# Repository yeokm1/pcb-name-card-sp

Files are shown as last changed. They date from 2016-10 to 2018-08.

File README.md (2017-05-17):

# pcb-name-card-sp

My name or business card that is on a Printed Circuit Board (PCB). Comes with an white LED, UV LED and a ruler. Not forgetting a QR code containing my contact details in [Vcard](https://en.wikipedia.org/wiki/VCard) format. This is an update to my [previous version](https://github.com/yeokm1/pcb-name-card) since I have changed my company.

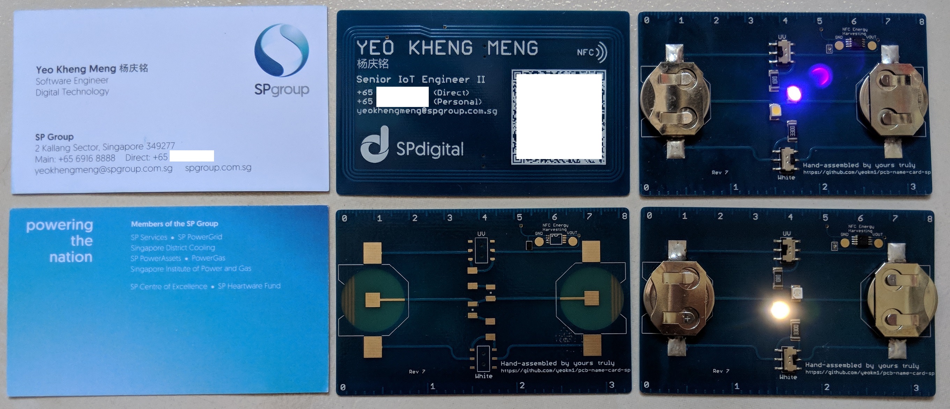
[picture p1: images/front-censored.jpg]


### PCB Design software and addons/references used

1. Eagle 8.0.2
2. Modified CR2032 library based on [here](https://github.com/nickaknudson/eagle-nickaknudson/blob/master/cr2032.lbr)
2. Elecrow Design Rule Check for 2 layers (in repo as `Elecrow_2-layer_eagle_rule.dru`)
3. Elecrow Gerber Generater 2-layer board (in repo as `Elecrow_Gerber_Generater_DrillAlign.cam`)
4. QR code generated from [here](http://goqr.me/)

### Schematic drawings

Image are exported from Eagle at 600dpi.

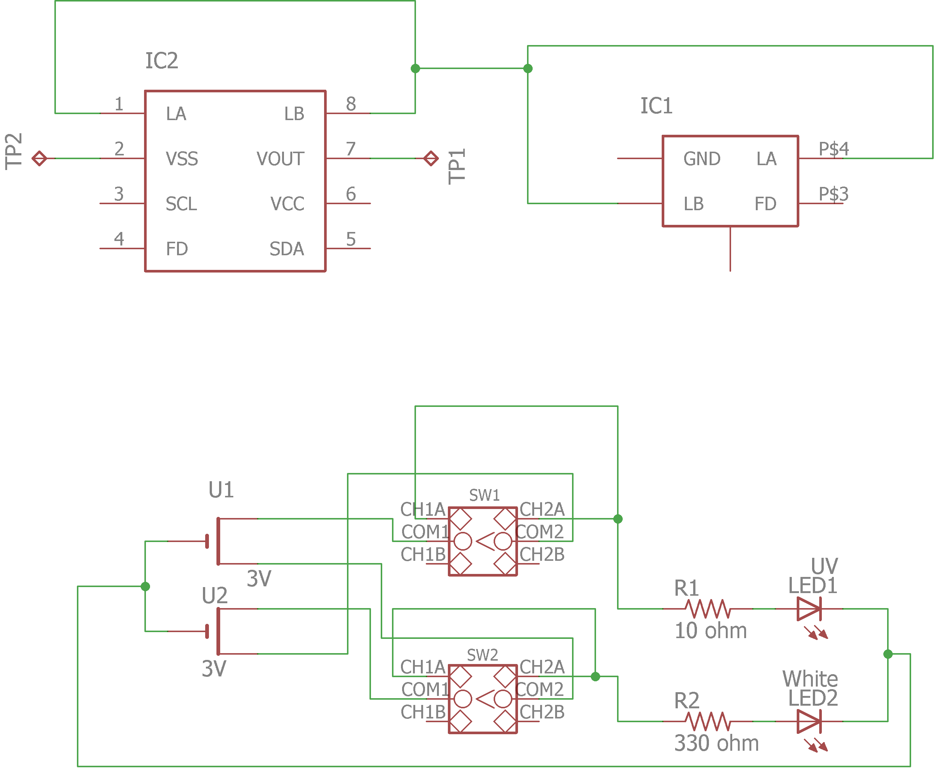
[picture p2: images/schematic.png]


The board schematic as seen in Eagle. The connections are slightly convoluted to prevent the traces from crossing in the board layout.

### Bill of Materials (BOM) for components only

Assume minimum order 10 pieces, cost in Singapore dollars. There are additional savings if I order more say 50 units but the savings are still small. Delivery for BOM not included.

The BOM is available in the odt spreadsheets in this repo.

### PCB fabrication

PCB fabrication is currently done by [Elecrow (10-pieces-link)](http://www.elecrow.com/10pcs-2-layer-pcb-p-1175.html) or [(50-pieces-link)](http://www.elecrow.com/50pcs-2-layer-pcb-enig-p-1172.html) based on the following settings. Remember to consult the order submission specifications at the bottom of the previous link before submitting. Use the provided Gerber generator to produce the Gerber files.

#### My Fabrication Settings:

1. Layer: 2
2. PCB Thickness: 0.6mm
3. Copper Weight : 1oz 35um (NA for 50 pieces)
4. PCB Size : 10cm Max * 10cm Max (or 50cm2 for 50 pieces)
5. PCB Color : Blue
6. Surface Finish: ENIG
7. PCB Stencil : NO Stencil
8. Lead time : Shipped in 4 to 7 days (NA for 50 pieces)
9. Panelizing : Single PCB with milling

# References
1. [How to design a 13.56 MHz
customized tag antenna](http://www.st.com/st-web-ui/static/active/jp/resource/technical/document/application_note/CD00221490.pdf)
2. [The impact of high pulse drain on CR2032 coin-cell battery capacity](http://m.eet.com/media/1121454/c0924post.pdf)
3. [Panasonic NFC Design Navigator](http://www.semicon.panasonic.co.jp/en/tool/nfcdesignnavigator/)

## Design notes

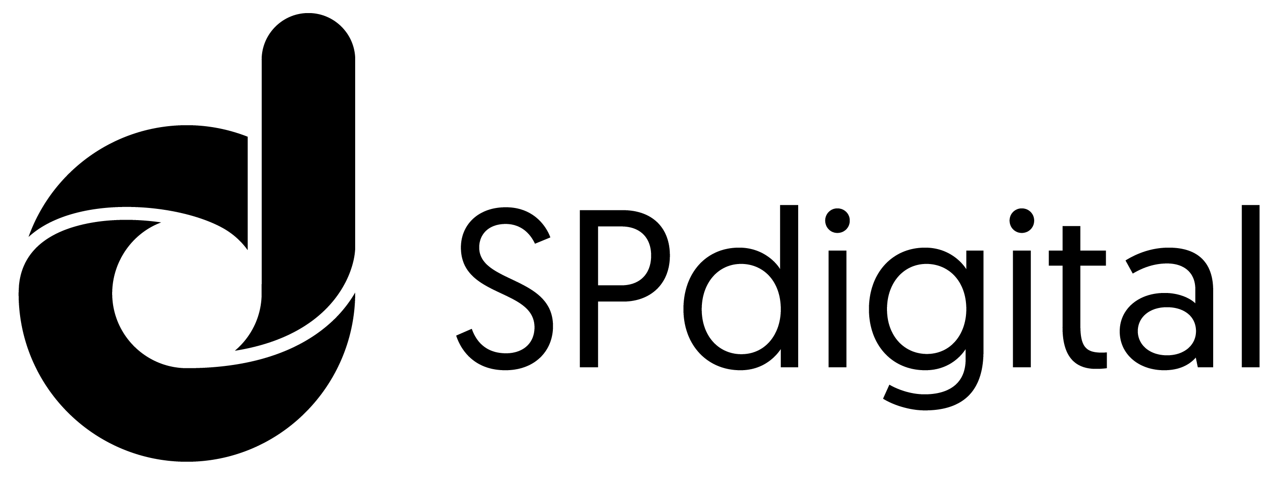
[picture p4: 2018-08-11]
sp-designs-rebrand/sp-digital.png

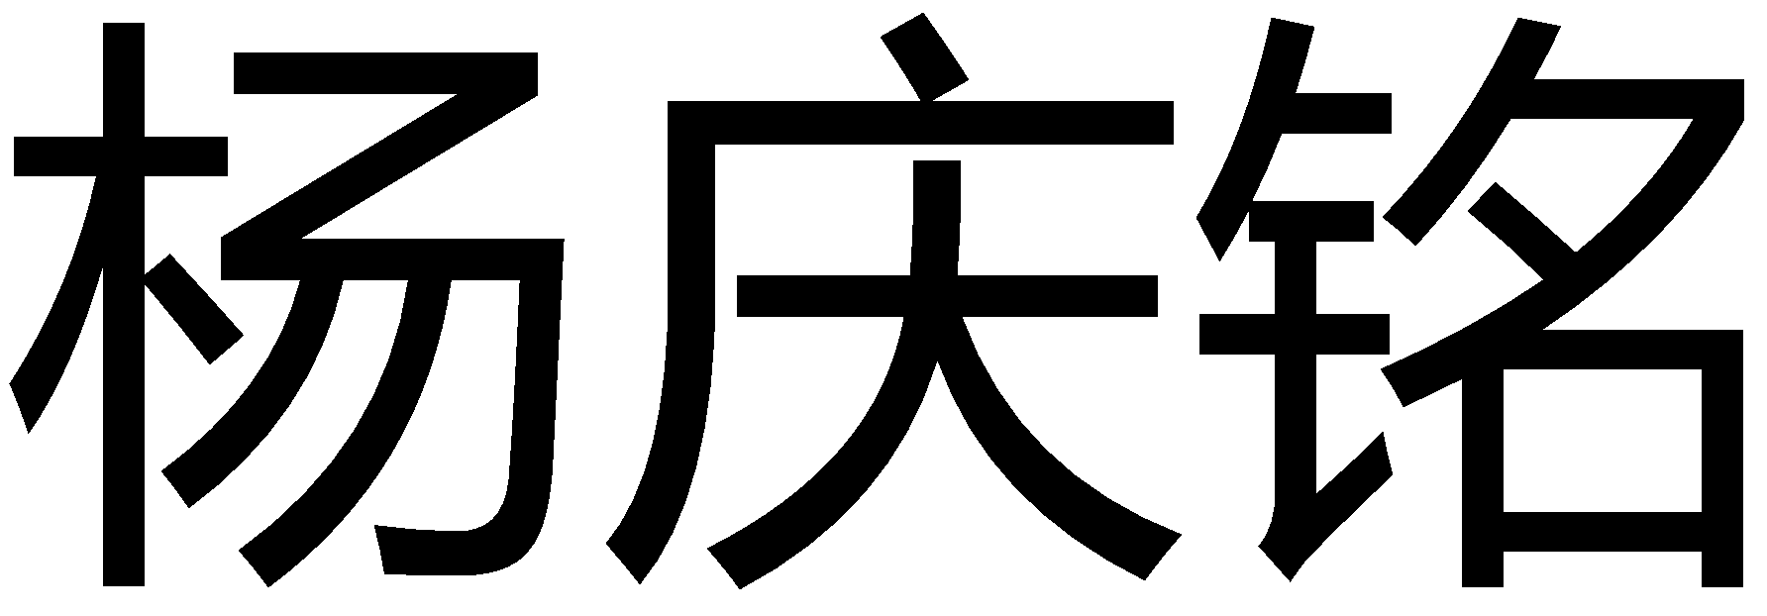
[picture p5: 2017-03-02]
sp-designs-rebrand/chinese-name.bmp

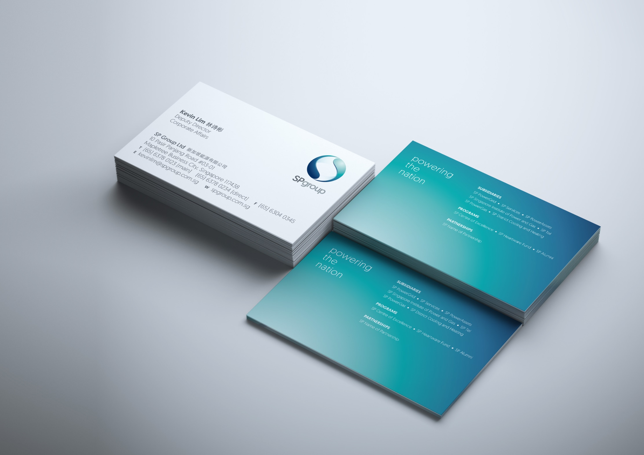
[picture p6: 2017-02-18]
sp-designs-rebrand/new card.png

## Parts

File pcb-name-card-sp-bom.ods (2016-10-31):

Part | Value | Device | Package | Manufacturer | Part number | Quantity | Unit Cost (10) | Total Unit Cost (10) | Unit Cost (50) | Total Unit Cost (50) | Source webpage
LED1 | UV | UV SMD LED | PLCC2 | Vishay | VLMU3100-GS08 | 1 | 0.469 | 0.469 | 0.469 | 0.469 | https://sg.rs-online.com/web/p/uv-leds/8184462/
LED2 | Neutral White | White SMD LED | PLCC2 | Avago Technologies | ASMT-UWB1-NX3E2 | 1 | 0.552 | 0.552 | 0.552 | 0.552 | http://sg.element14.com/avago-technologies/asmt-uwb1-nx3e2/led-smd-plcc2-neutral-white-4500k/dp/1895842
R1 | 10 ohm, ±1% | Surface Mount Chip Resistor, Thick Film, RC Series | R2010 | Yageo (Phycomp) | RC2010FK-0710RL | 1 | 0.228 | 0.228 | 0.228 | 0.228 | http://sg.element14.com/yageo-phycomp/rc2010fk-0710rl/resistor-prc111-2010-10r/dp/9235590
R2 | 330 ohm, ±1% | Surface Mount Chip Resistor, Thick Film, ASC Series | R2010 | Welwyn | ASC2010-330RFT4 | 1 | 0.149 | 0.149 | 0.149 | 0.149 | http://sg.element14.com/welwyn/asc2010-330rft4/resistor-anti-sulphur-2010-330r/dp/2079044
SW1, SW2 | - | Slide Switch, DPDT, Vertical, SMD | SW6-2.54-SMD-7.0X3.5X1.5MM | C & K Components | AYZ0202AGRLC | 2 | 2.07 | 4.14 | 1.81 | 3.62 | http://sg.element14.com/c-k-components/ayz0202agrlc/switch-dpdt-0-1a-12vdc-smd-on/dp/2319973
U1, U2 | 3V | CR2016 battery retainer (works for CR2025) | SMD holder | Linx Technologies Inc | BAT-HLD-002-SMT | 2 | 0.43 | 0.86 | 0.398 | 0.796 | http://www.digikey.sg/product-detail/en/0/BAT-HLD-002-SMT-ND
IC1 | 888 bytes | NTAG216 | HXSON-4 | NXP | NT2H1611F0DTLH | 1 | 1.15 | 1.15 | 1.15 | 1.15 | http://www.mouser.sg/Search/ProductDetail.aspx?R=NT2H1611F0DTLH
IC2 | 1904 bytes | NTAG I2C | TSSOP-8 | NXP | NT3H1201W0FTTJ | 0 | 1.63 | 0 | 1.63 | 0 | http://www.mouser.sg/Search/ProductDetail.aspx?R=NT3H1201W0FTTJ
- | 3V | CR2025 battery | CR2025 | Panasonic – BSG | CR-2025L/BN | 2 | 0.431 | 0.862 | 0.383 | 0.766 | http://www.digikey.sg/product-detail/en/0/P188-ND
- | ENIG, Blue | PCB manufacturing cost without stencil | 10cm x 10cm, 0.6mm thickness | Elecrow | - | 1 | 6.1 | 6.1 | 2.11 | 2.11 | http://www.elecrow.com/10pcs-2-layer-pcb-p-1175.html | http://www.elecrow.com/50pcs-2-layer-pcb-enig-p-1172.html
 |  |  |  |  |  |  | Subtotal | 14.51 |  | 9.84
 |  |  |  |  |  |  | GST 7% | 1.0157 |  | 0.6888
 |  |  |  |  |  |  | Total (SGD) | 15.5257 |  | 10.5288

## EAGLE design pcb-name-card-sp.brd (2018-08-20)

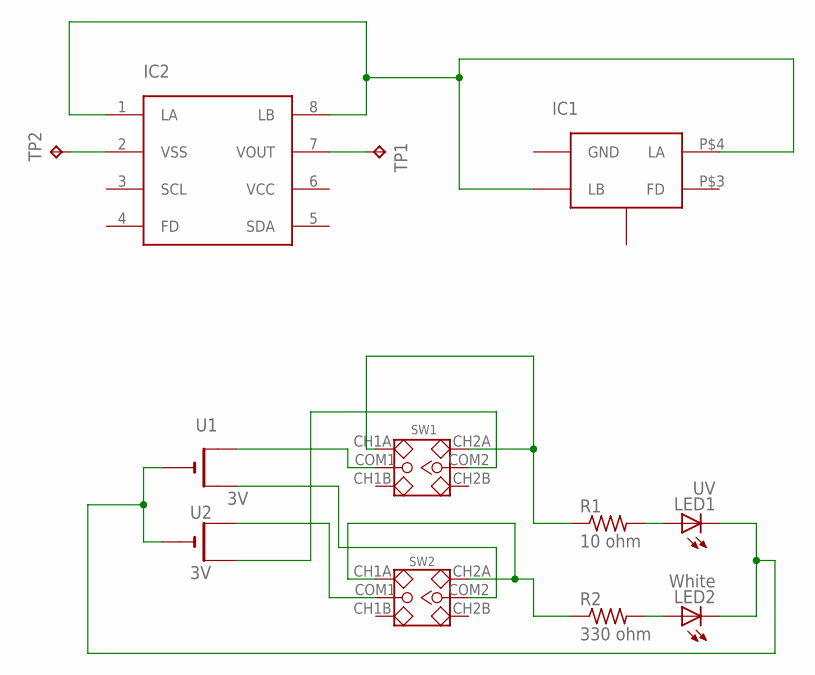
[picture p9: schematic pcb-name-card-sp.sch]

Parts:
IC1: NTAG21XFDRC-FIT; HXSON4-SMALL
IC2: NT3H1X01W0FTT; TSSOP-8
LED1: UV; PLCC2
LED2: White; PLCC2
R1: 10 ohm; R2010
R2: 330 ohm; R2010
SW1, SW2: SMD-TOGGLE-SWITCH-2CH(2X3P-7X3.5MM); SW6-2.54-SMD-7.0X3.5X1.5MM
TP1: VOUT; B2,54
TP2: GND; B2,54
U1, U2: 3V; CR2032-SMD

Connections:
unnamed: LED1.A, R1.2
unnamed: LED2.A, R2.2
unnamed: R2.1, SW2.CH1A, SW2.CH2A
unnamed: IC1.P$2 (LB), IC1.P$4 (LA), IC2.1 (LA), IC2.8 (LB)
unnamed: LED1.C, LED2.C, U1.-, U2.-
unnamed: SW1.COM1, U1.+$1 (+)
unnamed: IC2.2 (VSS), TP2.TP
unnamed: IC2.7 (VOUT), TP1.TP
unnamed: SW2.COM1, U2.+$1 (+)
unnamed: SW2.COM2, U1.+$2 (+1)
unnamed: SW1.COM2, U2.+$2 (+1)
unnamed: R1.1, SW1.CH1A, SW1.CH2A

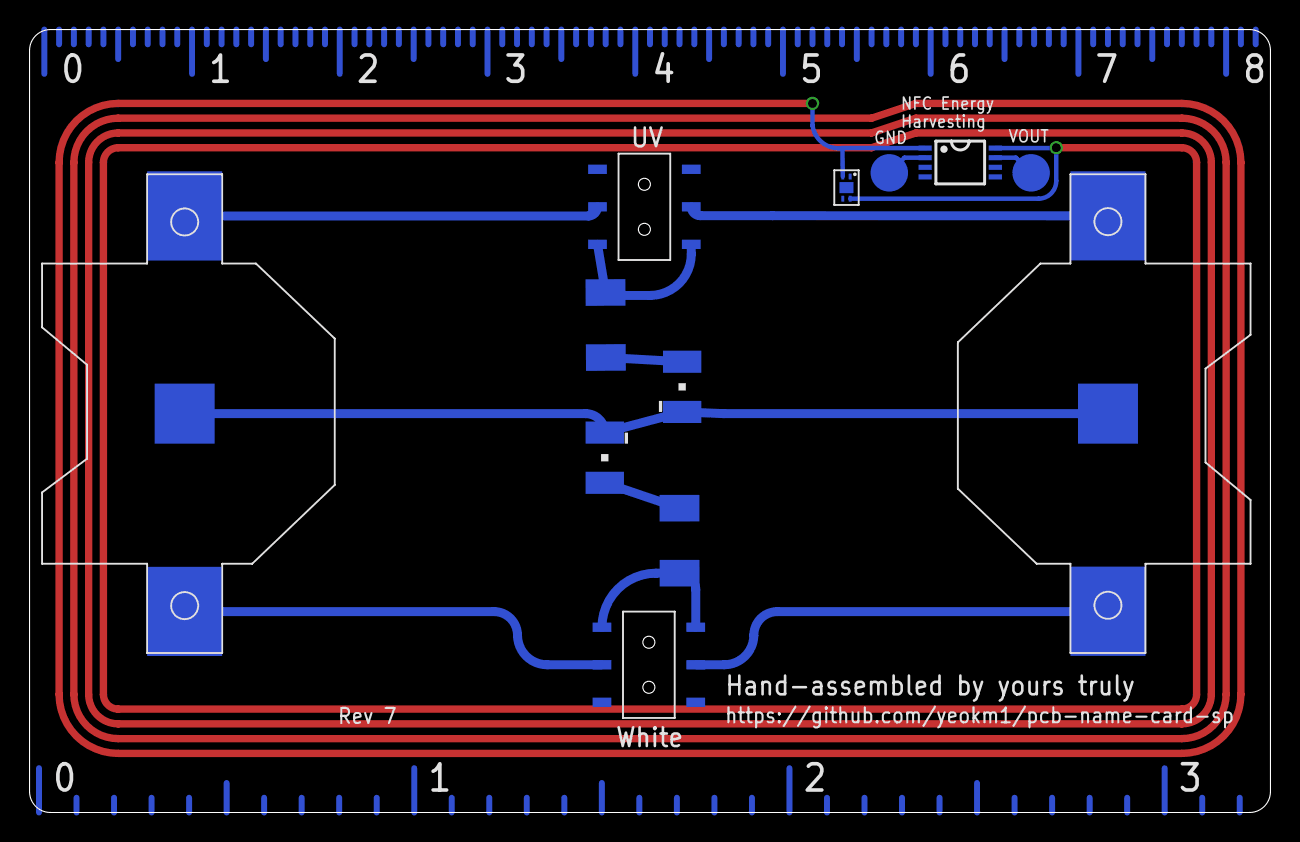
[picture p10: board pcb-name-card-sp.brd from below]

Board: 2 copper layers, 84.0 x 53.0 mm, 12 parts (12 on the bottom side), 12 nets.

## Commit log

2017-02-18 new card rebranded design
    [pcb-name-card-sp.brd]
2017-02-18 show all layers
    [pcb-name-card-sp.brd]
2017-02-18 rev2 gerber
2017-02-21 Adjusted logo position
    [pcb-name-card-sp.brd]
2017-02-21 rev3 gerber
    [pcb-name-card-sp.brd]
2017-02-28 add www to spgroup url
    [pcb-name-card-sp.brd]
2017-03-02 rev5 moves close to actual sp card
    [pcb-name-card-sp.brd, pcb-name-card-sp.sch]
2018-08-11 update new job title
    [pcb-name-card-sp.brd]
2018-08-11 change to spdigital logo
    [pcb-name-card-sp.brd]
2018-08-11 update to SP Digital
    [pcb-name-card-sp.brd]
2018-08-20 adjusted font sizes
    [pcb-name-card-sp.brd]
